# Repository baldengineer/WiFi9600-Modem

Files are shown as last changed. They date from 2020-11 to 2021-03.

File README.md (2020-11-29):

# WiFi9600 Modem
 Retro-cyling a Practical Peripherals 9600SA into a WiFiModem

Design files and code for WiFi9600.

As a kid, I had a Practical Peripherals 9600SA. For years I used it to connect to BBSes and then the Internet. At least, until I upgraded to a 56K USR Sportser.

This project removes the original electronics and replaces them with an ESP8266, MP3 Player, and some relays. It allows classic computers with a RS-232 port to connect to the internet via telnet. 

The MP3 player enables authentic fake modem sounds. And the relays are there for authentic real clicky-clicks.

Live stream archive of the project work is available here:
https://www.twitch.tv/baldengineer/videos

Watch the stream and help out in chat here:
https://twitch.tv/baldengineer

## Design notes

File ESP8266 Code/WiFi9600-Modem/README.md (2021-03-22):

sThe modem firmware is using the code from this project:  https://github.com/dhansel/WifiModem

Modifications include support for LED activity and playing sounds. 

There are also a couple of places where `millis()` isn't handled correctly. (When I'm done with my project, I'll fork and submit a PR.)

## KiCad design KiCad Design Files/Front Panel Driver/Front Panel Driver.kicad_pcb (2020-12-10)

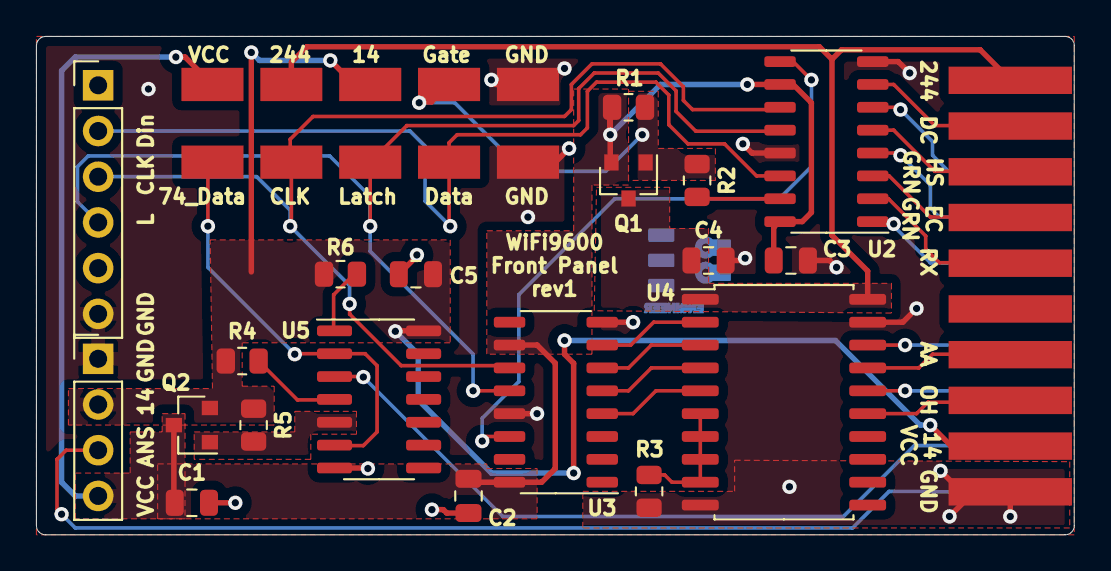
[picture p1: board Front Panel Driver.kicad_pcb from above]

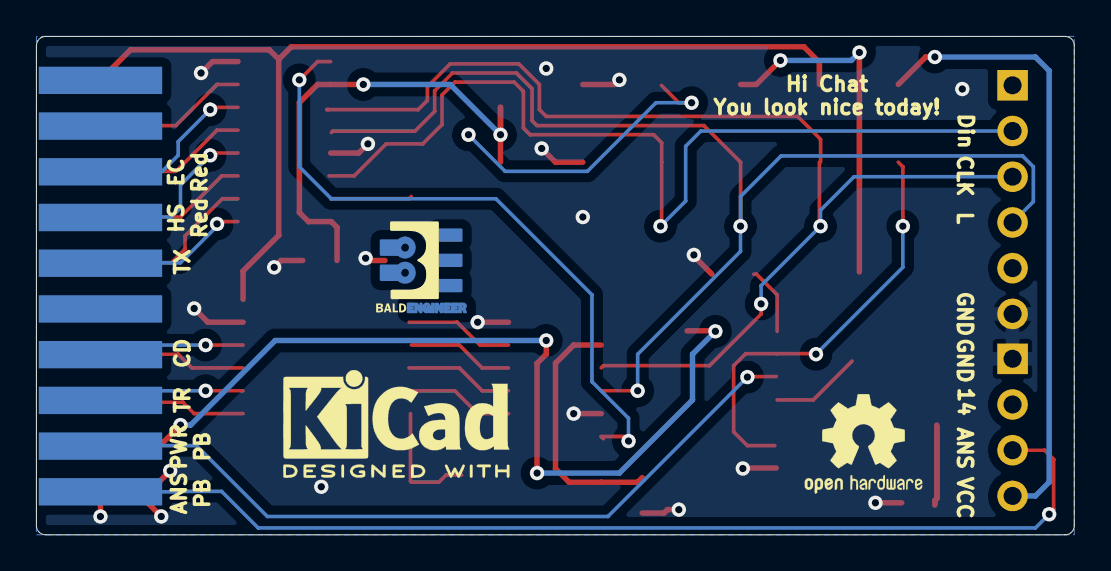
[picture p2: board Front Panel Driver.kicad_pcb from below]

Board: 2 copper layers, 57.7 x 27.7 mm, 31 parts (2 on the bottom side), 32 nets.

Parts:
C1, C2, C3, C4, C5: 1uF; C_0805_2012Metric
J9: Front_Panel; Edge_10mil_2x10
J10: PWR_HDR; PinHeader_1x04_P2.54mm_Vertical
J11: SH_HDR; PinHeader_1x06_P2.54mm_Vertical
Q1, Q2: P-NMOS; SOT-23
R1, R3, R4, R5, R6: 4k7; R_0805_2012Metric
R2: 1k; R_0805_2012Metric
TP1: TP_Panel_EN; Harwin-S1751-46-Test-Point
TP2: TP_244_VCC; Harwin-S1751-46-Test-Point
TP3: Data; Harwin-S1751-46-Test-Point
TP4: Clock; Harwin-S1751-46-Test-Point
TP5: Latch; Harwin-S1751-46-Test-Point
TP6: TP_74_Data; Harwin-S1751-46-Test-Point
TP7: TP_14_VCC; Harwin-S1751-46-Test-Point
TP8: TP_VCC; Harwin-S1751-46-Test-Point
TP9: TP_GND1; Harwin-S1751-46-Test-Point
TP10: TP_GND2; Harwin-S1751-46-Test-Point
U2, U3: 74HCT595; SO-16_3.9x9.9mm_P1.27mm
U4: 74HCT245; SOIC-20W_7.5x12.8mm_P1.27mm
U5: 74HCT74; SOIC-14_3.9x8.7mm_P1.27mm
svg2mod: G***; BE5

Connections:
/14-VCC: C5.1, J9.12, J10.2, Q2.2, R4.1, R5.1, R6.2, TP7.1, U5.14
/244-VCC: C4.1, J9.20, Q1.3, TP2.1, U4.1, U4.20
/AA: J9.14, U4.17
/ANS-PB: J9.10, J10.3
/CD: J9.7, U4.18
/DC: J9.19, U2.7
/Data-In: J11.2, TP3.1, U2.14
/EC-GRN: J9.17, U2.3
/EC-Red: J9.3, U2.6
/FF-DATA: TP6.1, U5.2, U5.6
/Gate244: Q1.1, R1.1, R2.1, TP1.1
/HS-GRN: J9.18, U2.5
/HS-Red: J9.4, U2.4
/Latch: J11.4, TP5.1, U2.12, U3.12
/OH: J9.13, U4.15
/PWR-PB: J9.9, U5.3
/Panel-En: R2.2, U2.15
/RX: J9.16, U2.2
/SH1: U3.4, U4.5
/SH2: U3.5, U4.4
/SH3: U3.6, U4.3
/SH4: U3.7, U4.2
/SH-Carry: U2.9, U3.14
/Ser-Clock: J11.3, TP4.1, U2.11, U3.11
/TR: J9.8, U4.16
/TX: J9.5, U2.1
GND: C1.2, C2.2, C3.2, C4.2, C5.2, J9.11, J10.1, J11.6, R3.2, TP9.1, TP10.1, U2.8, U2.13, U3.8, U3.13, U4.10, U4.19, U5.7
unnamed: Q2.1, R5.2, U5.5
unnamed: R3.1, U4.6, U4.7, U4.8, U4.9
unnamed: R4.2, U5.4
unnamed: R6.1, U5.1
VCC: C1.1, C2.1, C3.1, J10.4, Q1.2, Q2.3, R1.2, TP8.1, U2.10, U2.16, U3.10, U3.16

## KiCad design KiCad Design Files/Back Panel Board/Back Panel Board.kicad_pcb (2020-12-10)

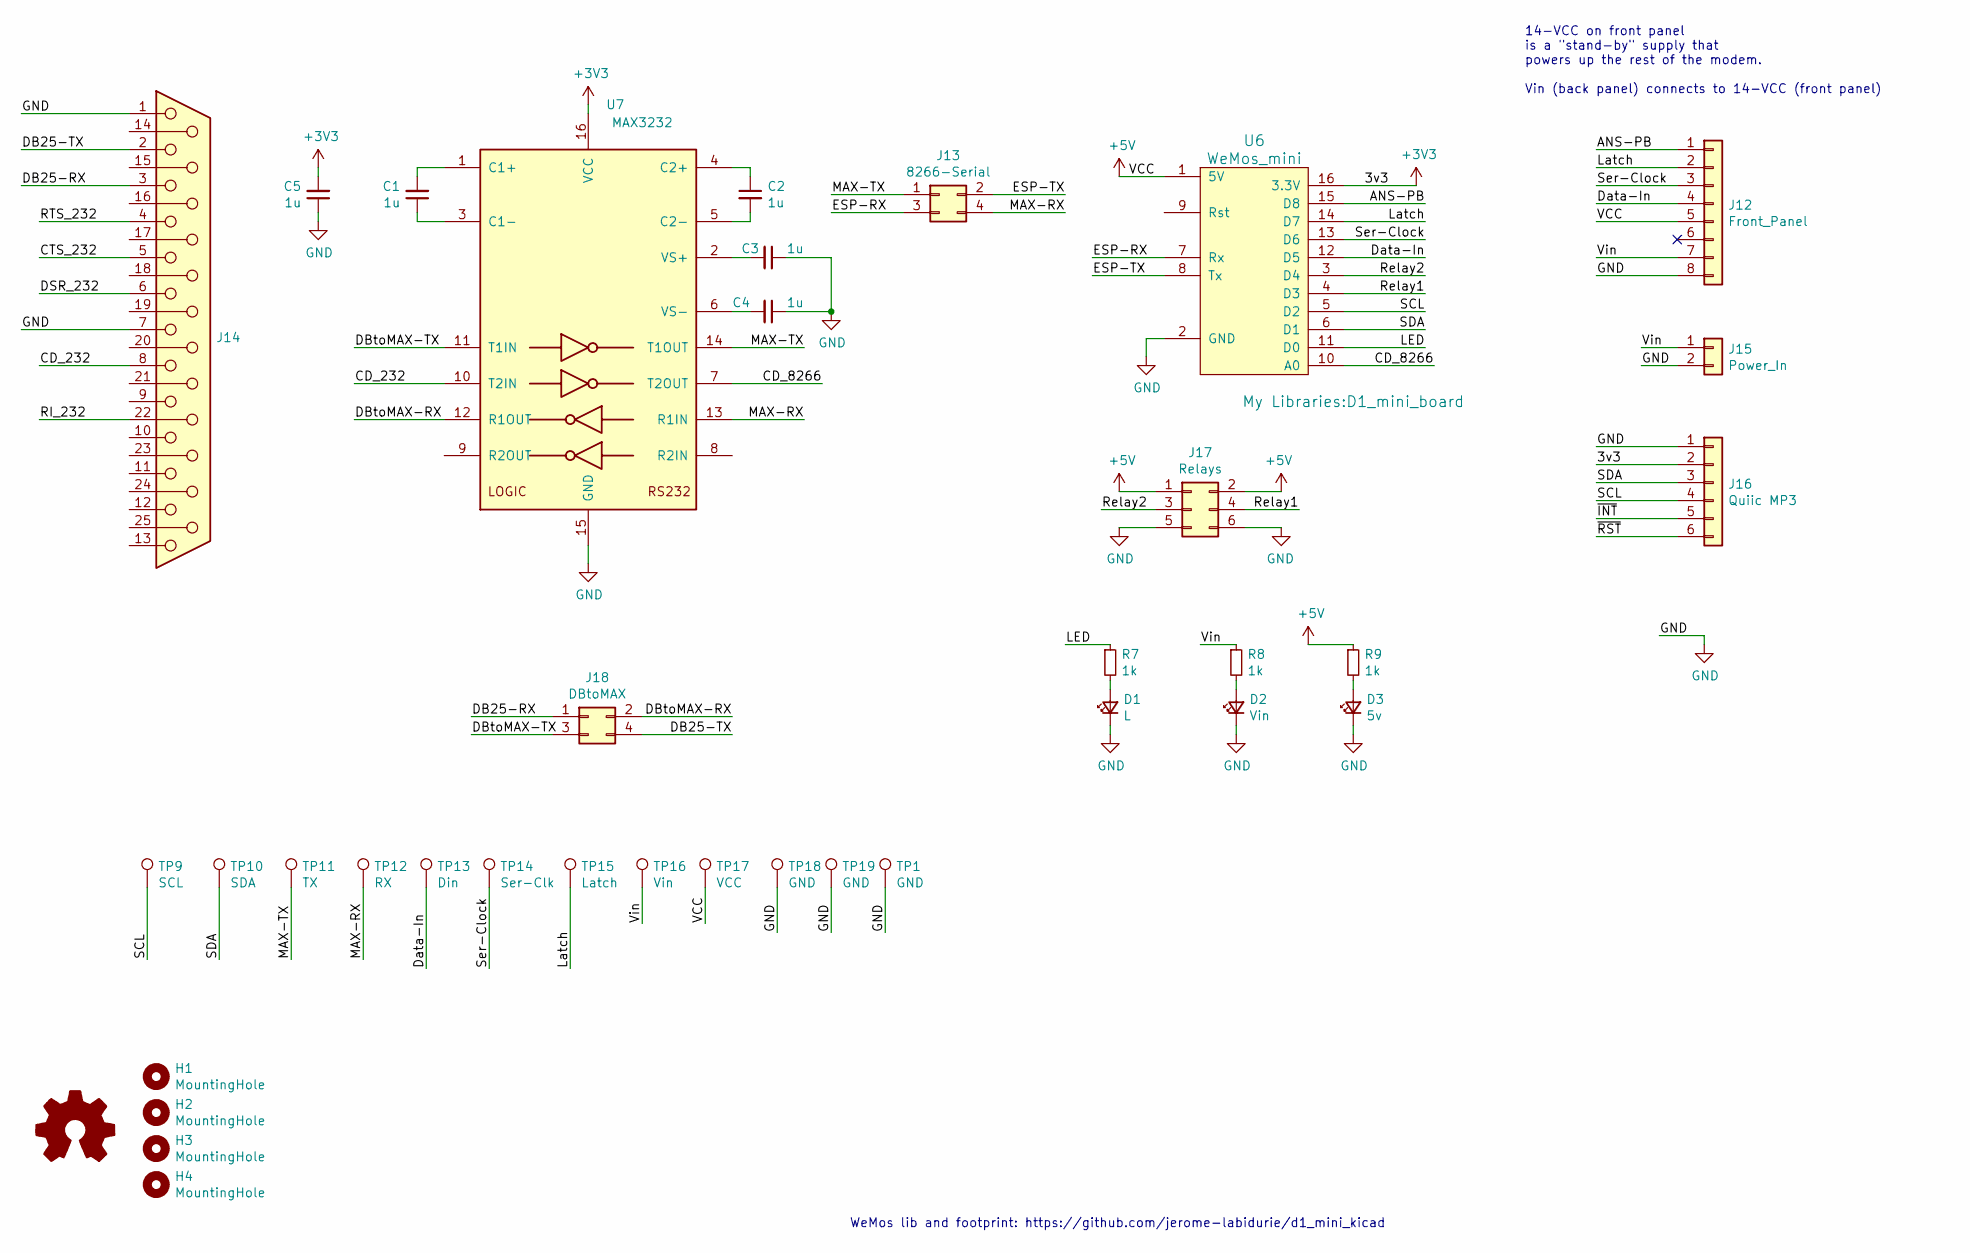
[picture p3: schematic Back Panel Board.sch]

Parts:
C1, C2, C3, C4, C5: 1u; C_0805_2012Metric
D1: L; LED_1206_3216Metric
D2: Vin; LED_1206_3216Metric
D3: 5v; LED_1206_3216Metric
H1, H2, H3, H4: MountingHole; MountingHole_2.5mm
J12: Front_Panel; PinHeader_1x08_P2.54mm_Vertical
J13: 8266-Serial; PinHeader_2x02_P2.54mm_Vertical
J14: DB25_Female_MountingHoles; DSUB-25_Female_EdgeMount_P2.77mm
J15: Power_In; PinHeader_1x02_P2.54mm_Vertical
J16: Quiic MP3; PinHeader_1x06_P2.54mm_Vertical
J17: Relays; PinHeader_2x03_P2.54mm_Vertical
J18: DBtoMAX; PinHeader_2x02_P2.54mm_Vertical
R7, R8, R9: 1k; R_0805_2012Metric
TP1, TP18, TP19: GND; Harwin-S1751-46-Test-Point
TP9: SCL; Harwin-S1751-46-Test-Point
TP10: SDA; Harwin-S1751-46-Test-Point
TP11: TX; Harwin-S1751-46-Test-Point
TP12: RX; Harwin-S1751-46-Test-Point
TP13: Din; Harwin-S1751-46-Test-Point
TP14: Ser-Clk; Harwin-S1751-46-Test-Point
TP15: Latch; Harwin-S1751-46-Test-Point
TP16: Vin; Harwin-S1751-46-Test-Point
TP17: VCC; Harwin-S1751-46-Test-Point
U6: WeMos_mini; D1_mini_board
U7: MAX3232; SOIC-16W_7.5x10.3mm_P1.27mm

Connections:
+3V3: C5.2, J16.2, U6.16 (3.3V), U7.16 (VCC)
+5V: J12.5, J17.1, J17.2, R9.1, TP17.1, U6.1 (5V)
/ANS-PB: J12.1, U6.15 (D8)
/CD_232: J14.8, U7.10 (T2IN)
/CD_8266: U6.10 (A0), U7.7 (T2OUT)
/CTS_232: J14.5
/DB25-RX: J14.3, J18.1
/DB25-TX: J14.2, J18.4
/DBtoMAX-RX: J18.2, U7.12 (R1OUT)
/DBtoMAX-TX: J18.3, U7.11 (T1IN)
/DSR_232: J14.6
/Data-In: J12.4, TP13.1, U6.12 (D5)
/ESP-RX: J13.3, U6.7 (Rx)
/ESP-TX: J13.2, U6.8 (Tx)
/LED: R7.1, U6.11 (D0)
/Latch: J12.2, TP15.1, U6.14 (D7)
/MAX-RX: J13.4, TP12.1, U7.13 (R1IN)
/MAX-TX: J13.1, TP11.1, U7.14 (T1OUT)
/RI_232: J14.22
/RTS_232: J14.4
/Relay1: J17.4, U6.4 (D3)
/Relay2: J17.3, U6.3 (D4)
/SCL: J16.4, TP9.1, U6.5 (D2)
/SDA: J16.3, TP10.1, U6.6 (D1)
/Ser-Clock: J12.3, TP14.1, U6.13 (D6)
/Vin: J12.7, J15.1, R8.1, TP16.1
/~INT: J16.5
/~RST: J16.6
GND: C3.1, C4.1, C5.1, D1.1 (K), D2.1 (K), D3.1 (K), J12.8, J14.1, J14.7, J15.2, J16.1, J17.5, J17.6, TP1.1, TP18.1, TP19.1, U6.2 (GND), U7.15 (GND)
unnamed: C1.1, U7.3 (C1-)
unnamed: C1.2, U7.1 (C1+)
unnamed: C2.1, U7.4 (C2+)
unnamed: C2.2, U7.5 (C2-)
unnamed: C3.2, U7.2 (VS+)
unnamed: C4.2, U7.6 (VS-)
unnamed: D1.2 (A), R7.2
unnamed: D2.2 (A), R8.2
unnamed: D3.2 (A), R9.2

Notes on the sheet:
14-VCC on front panel is a "stand-by" supply that powers up the rest of the modem. Vin (back panel) connects to 14-VCC (front panel)
WeMos lib and footprint: https://github.com/jerome-labidurie/d1_mini_kicad

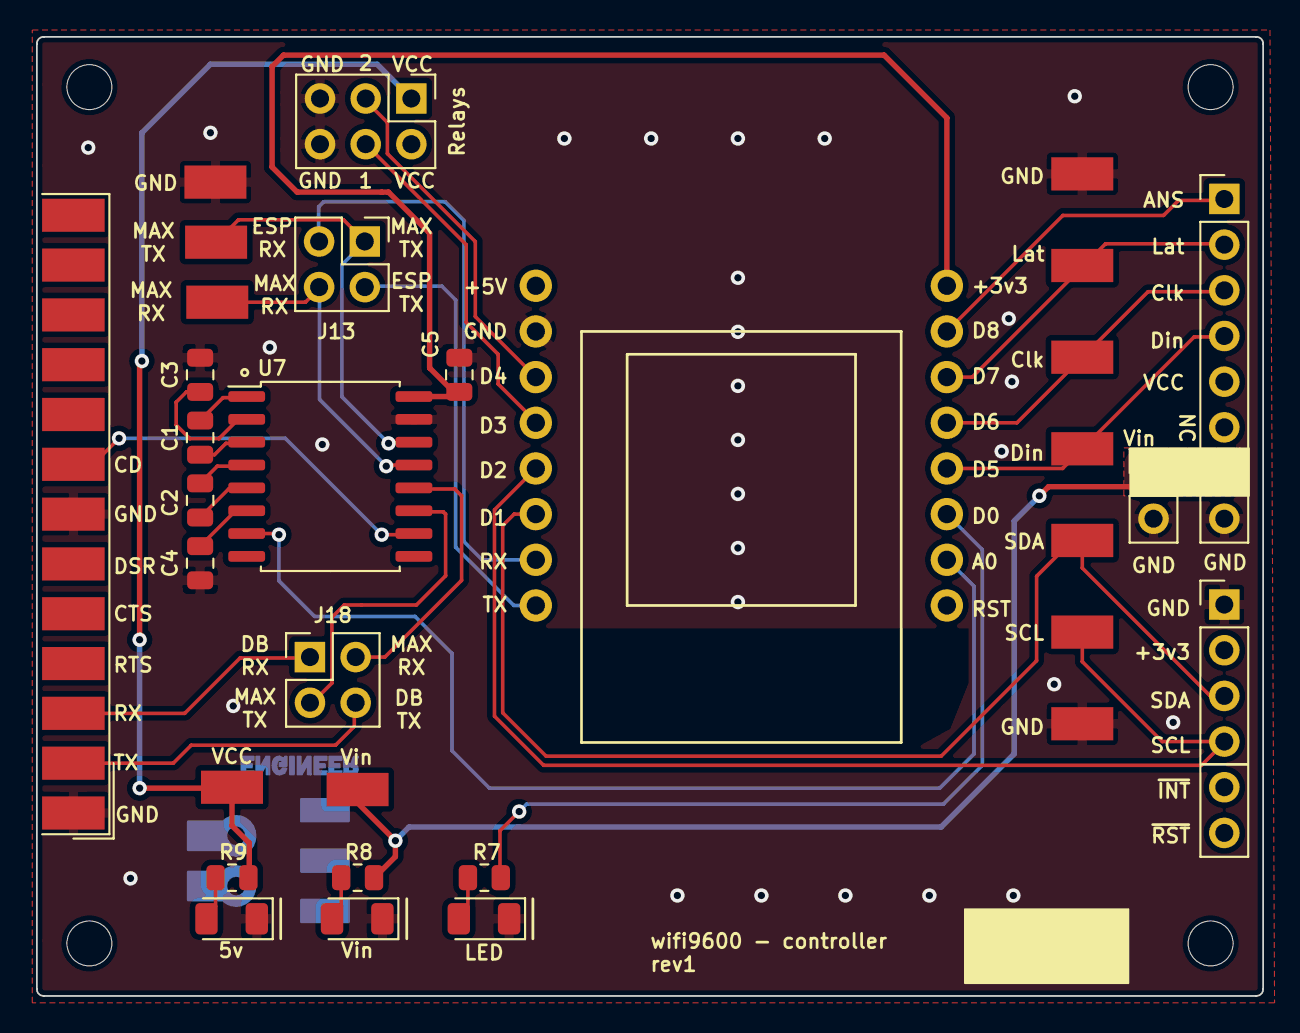
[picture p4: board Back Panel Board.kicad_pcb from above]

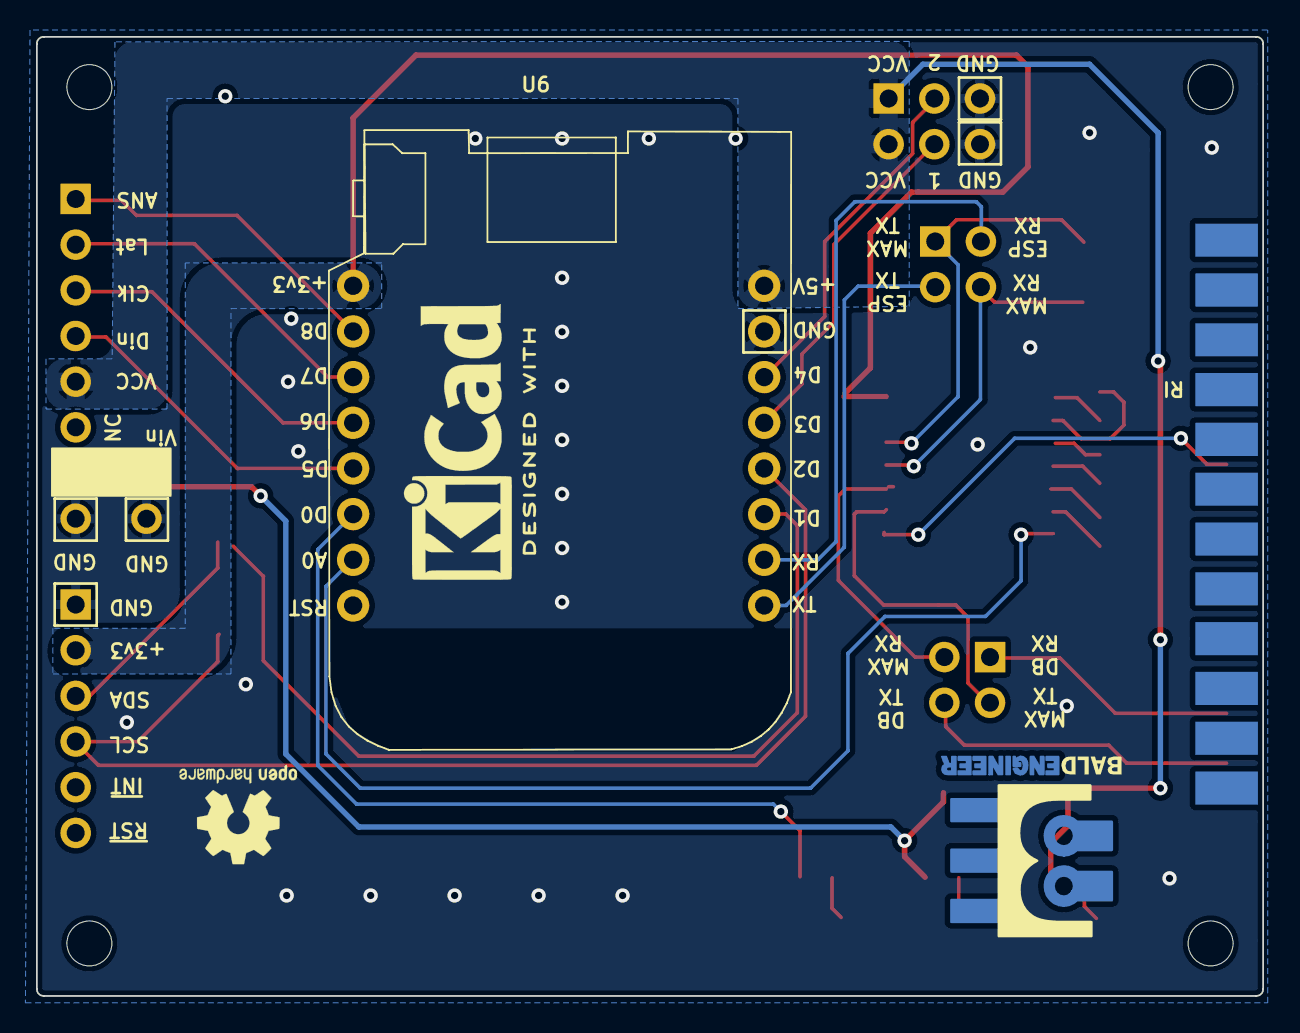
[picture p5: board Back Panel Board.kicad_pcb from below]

Board: 2 copper layers, 68.2 x 53.3 mm, 37 parts (2 on the bottom side), 32 nets.

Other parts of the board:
svg2mod: G***; BE10

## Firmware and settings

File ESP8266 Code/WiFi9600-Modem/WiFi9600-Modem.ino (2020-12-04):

// This code originally based on 
// WiFi Modem and Telnet Server
// Copyright (C) 2018 David Hansel
// -----------------------------------------------------------------------------
// Modifications by James Lewis @baldengineer
// WiFi9600 Practical Perpherials 9600SA Retro Cycling

#include <ESP8266WiFi.h>
#include <ESP8266WebServer.h>
#include <ESP8266mDNS.h>
#include <EEPROM.h>

#include <Wire.h> //Needed for I2C to Qwiic MP3 Trigger

#include "WiFi9600-Modem.h"

//how many clients should be able to telnet to this ESP8266
#define MAX_SRV_CLIENTS 3

WiFiServer server(23);
WiFiClient serverClients[MAX_SRV_CLIENTS], modemClient;
ESP8266WebServer webserver(80);
unsigned long prevCharTime = 0;
uint8_t modemEscapeState = 0, modemExtCodes = 0, modemReg[255];
bool    modemCommandMode = true, modemEcho = true, modemQuiet = false, modemVerbose = true;


static int linespeeds[] = {0, 75, 110, 300, 600, 1200, 2400, 4800, 7200, 9600, 12000, 14400};
#define NSPEEDS (sizeof(linespeeds)/sizeof(int))

#define REG_ESC            2
#define REG_CR             3
#define REG_LF             4
#define REG_BSP            5
#define REG_GUARDTIME     12
#define REG_LINESPEED     37
#define REG_CURLINESPEED  43

#define RELAY_ON LOW
#define RELAY_OFF HIGH

enum  {
    E_OK = 0,
    E_CONNECT,
    E_RING,
    E_NOCARRIER,
    E_ERROR,
    E_CONNECT1200,
    E_NODIALTONE,
    E_BUSY,
    E_NOANSWER,
    E_CONNECT600,
    E_CONNECT2400,
    E_CONNECT4800,
    E_CONNECT9600,
    E_CONNECT14400,
    E_CONNECT19200
  };

struct TelnetStateStruct {
  uint8_t cmdLen;
  uint8_t cmd[4];
  bool sendBinary;
  bool receiveBinary;
  bool receivedCR;
  bool subnegotiation;
} modemTelnetState, clientTelnetState[MAX_SRV_CLIENTS];


#define MAGICVAL 0xF0E1D2C3B4A59687
struct WiFiDataStruct {
  uint64_t magic;
  char     ssid[256];
  char     key[256];
} WifiData;


struct SerialDataStruct {
  uint64_t magic;
  uint32_t baud;
  byte     bits;
  byte     parity;
  byte     stopbits;
  byte     silent;
  byte     handleTelnetProtocol;
  char     telnetTerminalType[100];
} SerialData;


SerialConfig GetSerialConfig() {
  if( SerialData.bits==5 && SerialData.parity==0 && SerialData.stopbits==1 )
    return SERIAL_5N1;
  else if( SerialData.bits==5 && SerialData.parity==0 && SerialData.stopbits==2 )
    return SERIAL_5N2;
  else if( SerialData.bits==5 && SerialData.parity==1 && SerialData.stopbits==1 )
    return SERIAL_5E1;
  else if( SerialData.bits==5 && SerialData.parity==1 && SerialData.stopbits==2 )
    return SERIAL_5E2;
  else if( SerialData.bits==5 && SerialData.parity==2 && SerialData.stopbits==1 )
    return SERIAL_5O1;
  else if( SerialData.bits==5 && SerialData.parity==2 && SerialData.stopbits==2 )
    return SERIAL_5O2;
  else if( SerialData.bits==6 && SerialData.parity==0 && SerialData.stopbits==1 )
    return SERIAL_6N1;
  else if( SerialData.bits==6 && SerialData.parity==0 && SerialData.stopbits==2 )
    return SERIAL_6N2;
  else if( SerialData.bits==6 && SerialData.parity==1 && SerialData.stopbits==1 )
    return SERIAL_6E1;
  else if( SerialData.bits==6 && SerialData.parity==1 && SerialData.stopbits==2 )
    return SERIAL_6E2;
  else if( SerialData.bits==6 && SerialData.parity==2 && SerialData.stopbits==1 )
    return SERIAL_6O1;
  else if( SerialData.bits==6 && SerialData.parity==2 && SerialData.stopbits==2 )
    return SERIAL_6O2;
  else if( SerialData.bits==7 && SerialData.parity==0 && SerialData.stopbits==1 )
    return SERIAL_7N1;
  else if( SerialData.bits==7 && SerialData.parity==0 && SerialData.stopbits==2 )
    return SERIAL_7N2;
  else if( SerialData.bits==7 && SerialData.parity==1 && SerialData.stopbits==1 )
    return SERIAL_7E1;
  else if( SerialData.bits==7 && SerialData.parity==1 && SerialData.stopbits==2 )
    return SERIAL_7E2;
  else if( SerialData.bits==7 && SerialData.parity==2 && SerialData.stopbits==1 )
    return SERIAL_7O1;
  else if( SerialData.bits==7 && SerialData.parity==2 && SerialData.stopbits==2 )
    return SERIAL_7O2;
  else if( SerialData.bits==8 && SerialData.parity==0 && SerialData.stopbits==1 )
    return SERIAL_8N1;
  else if( SerialData.bits==8 && SerialData.parity==0 && SerialData.stopbits==2 )
    return SERIAL_8N2;
  else if( SerialData.bits==8 && SerialData.parity==1 && SerialData.stopbits==1 )
    return SERIAL_8E1;
  else if( SerialData.bits==8 && SerialData.parity==1 && SerialData.stopbits==2 )
    return SERIAL_8E2;
  else if( SerialData.bits==8 && SerialData.parity==2 && SerialData.stopbits==1 )
    return SERIAL_8O1;
  else if( SerialData.bits==8 && SerialData.parity==2 && SerialData.stopbits==2 )
    return SERIAL_8O2;
  else
    return SERIAL_8N1;
}


void applySerialSettings() {
  Serial.flush();
  Serial.end();
  delay(100);
  Serial.begin(SerialData.baud, GetSerialConfig());
}


const int   baud[]   = {110, 150, 300, 600, 1200, 2400, 4800, 9600, 19200, 38400, 57600, 115200, 256000, 512000, 921600, 0};
const int   bits[]   = {5, 6, 7, 8, 0};
const char *parity[] = {"No parity", "Even parity", "Odd parity", NULL};
const char *stop[]   = {"One stop bit", "Two stop bits", NULL};


void handleRoot() {
  char buffer2[100];
  String s;
  int i;

  s = ("<html>\n"
       "<head>\n"
       "<title>ESP8266 Telnet-to-Serial Bridge</title>\n"
       "</head>\n"
       "<body>\n"
       "<h1>ESP8266 Telnet-to-Serial Bridge</h1>\n");

  s += "<h2>Baud rate</h1>\n<ul>\n";
  for(i=0; baud[i]; i++)
    {
      if( (i==0 || baud[i-1]<SerialData.baud) && baud[i] > SerialData.baud )
        {
          snprintf(buffer2, 100, "<li><b>%i baud</b></li>", SerialData.baud);
          s += String(buffer2);
        }
      
      if( baud[i] == SerialData.baud )
        snprintf(buffer2, 100, "<li><b>%i baud</b></li>", baud[i]);
      else 
        snprintf(buffer2, 100, "<li><a href=\"set?baud=%i\">%i baud</a></li>", baud[i], baud[i]);
      
      s += String(buffer2);
    }


  s += "</ul>\n<h2>Data bits</h2>\n<ul>\n";
  for(i=0; bits[i]; i++)
    {
      if( SerialData.bits == bits[i] )
        snprintf(buffer2, 100, "<li><b>%i bits</b></li>", bits[i]);
      else 
        snprintf(buffer2, 100, "<li><a href=\"set?bits=%i\">%i bits</a></li>", bits[i], bits[i]);
      
      s += String(buffer2);
    }


  s += "</ul>\n<h2>Parity</h2>\n<ul>\n";
  for(i=0; parity[i]; i++)
    {
      if( SerialData.parity == i )
        snprintf(buffer2, 100, "<li><b>%s</b></li>", parity[i]);
      else
        snprintf(buffer2, 100, "<li><a href=\"set?parity=%c\">%s</a></li>", parity[i][0], parity[i]);

      s += String(buffer2);
    }

  s += "</ul>\n<h2>Stop bits</h2>\n<ul>\n";
  for(i=0; stop[i]; i++)
    {
      if( SerialData.stopbits == i+1 )
        snprintf(buffer2, 100, "<li><b>%s</b></li>", stop[i]); 
      else 
        snprintf(buffer2, 100, "<li><a href=\"set?stopbits=%i\">%s</a></li>", i+1, stop[i]);

      s += String(buffer2);
    }

  s += "</ul>\n<h2>Show WiFi connection information</h2>\n<ul>\n";
  if( SerialData.silent )
    {
      s += "<li><a href=\"set?silent=no\">Print to serial port after connecting</a></li>\n";
      s += "<li><b>Do not show</b></li>\n";
    }
  else
    {
      s += "<li><b>Print to serial port after connecting</b></li>\n";
      s += "<li><a href=\"set?silent=yes\">Do not show</a></li>\n";
    }
  
  s += "</ul>\n<h2>Telnet protocol</h2>\n<ul>\n";
  if( SerialData.handleTelnetProtocol )
    {
      int i;
      const char *terminalTypes[] = {"none", "ansi", "teletype-33", "unknown", "vt100", "xterm", NULL};

      s += "<li><b>Handle</b> - Report terminal type: ";
      bool found = false;
      for(i=0; terminalTypes[i]!=NULL; i++)
        {
          if( i>0 ) s += ", ";
          if( strcmp(terminalTypes[i], SerialData.telnetTerminalType)==0 || (i==0 && SerialData.telnetTerminalType[0]==0) )
            { s += "<b>" + String(terminalTypes[i]) + "</b>"; found = true; }
          else
            {
              snprintf(buffer2, 100, "<a href=\"set?telnetTerminalType=%s\">%s</a>", terminalTypes[i], terminalTypes[i]);
              s += String(buffer2);
            }
        }

      if( !found ) s += ", <b>" + String(SerialData.telnetTerminalType) + "</b>";
      s += "</li>\n";
      s += "<li><a href=\"set?filterTelnet=no\">Pass through</a></li>\n";
    }
  else
    {
      s += "<li><a href=\"set?filterTelnet=yes\">Handle</a></li>\n";
      s += "<li><b>Pass through</b></li>\n";
    }
  
  s += "</ul>\n</body>\n</html>";
  webserver.send(200, "text/html", s);
}


void handleSet()
{
  bool ok = webserver.args()>0;
  for(int i=0; i<ok && webserver.args(); i++)
    {
      if( webserver.argName(i) == "baud" )
        SerialData.baud = atoi(webserver.arg(i).c_str());
      else if( webserver.argName(i) == "bits" )
        {
          byte bits = atoi(webserver.arg(i).c_str());
          if( bits>=5 && bits<=8 )
            SerialData.bits = bits;
          else
            ok = false;
        }
      else if( webserver.argName(i) == "parity" && webserver.arg(i)=="N" )
        SerialData.parity = 0;
      else if( webserver.argName(i) == "parity" && webserver.arg(i)=="E" )
        SerialData.parity = 1;
      else if( webserver.argName(i) == "parity" && webserver.arg(i)=="O" )
        SerialData.parity = 2;
      else if( webserver.argName(i) == "stopbits" && webserver.arg(i)=="1" )
        SerialData.stopbits = 1;
      else if( webserver.argName(i) == "stopbits" && webserver.arg(i)=="2" )
        SerialData.stopbits = 2;
      else if( webserver.argName(i) == "silent" && webserver.arg(i)=="yes" )
        SerialData.silent = true;
      else if( webserver.argName(i) == "silent" && webserver.arg(i)=="no" )
        SerialData.silent = false;
      else if( webserver.argName(i) == "filterTelnet" && webserver.arg(i)=="log" )
        SerialData.handleTelnetProtocol = 2;
      else if( webserver.argName(i) == "filterTelnet" && webserver.arg(i)=="yes" )
        SerialData.handleTelnetProtocol = 1;
      else if( webserver.argName(i) == "filterTelnet" && webserver.arg(i)=="no" )
        SerialData.handleTelnetProtocol = 0;
      else if( webserver.argName(i) == "telnetTerminalType" )
        {
          int j;
          String ts = webserver.arg(i);
          for(j=0; j<99 && j<ts.length() && ts[j]>=32 && ts[j]<127; j++)
            SerialData.telnetTerminalType[j] = ts[j];
          SerialData.telnetTerminalType[j] = 0;
        }
      else
        ok = false;
    }

  if( ok ) 
    {
      EEPROM.put(768, SerialData);
      EEPROM.commit();
      applySerialSettings();
    }

  handleRoot();
}


void handleNotFound() 
{
  String message = "File Not Found\n\n";
  message += "URI: ";
  message += webserver.uri();
  message += "\nMethod: ";
  message += (webserver.method() == HTTP_GET) ? "GET" : "POST";
  message += "\nArguments: ";
  message += webserver.args();
  message += "\n";

  for (uint8_t i = 0; i < webserver.args(); i++)
    message += " " + webserver.argName(i) + ": " + webserver.arg(i) + "\n";

  webserver.send(404, "text/plain", message);
}


void readString(char *buffer, int buflen, bool password)
{
  int len = 0;
  while( true )
  {
    if( Serial.available() )
      {
        char c = Serial.read();
        if( c==10 || c==13 )
          {
            buffer[len] = 0;
            //Serial.print("Password: '");
            //Serial.print(buffer);
            //Serial.println("'");
            return;
          }
        else if( (c==8 || c==127) && len>0 )
          {
            Serial.print(char(8)); Serial.print(' '); Serial.print(char(8));
            len--;
          }
        else if( c >= 32 && len<buflen-1 )
          {
            buffer[len++] = c;
            Serial.print(password ? '*' : c);
          }
      }
    else
      delay(10);
    
    yield();
  }
  
}


void clearSerialBuffer()
{
  // empty the serial buffer
  delay(100); 
  while( Serial.available()>0 ) { Serial.read(); delay(10); }
}


void GetWiFiData(const char *msg)
{
  clearSerialBuffer();

  bool go = true;
  while( go )
  {
     Serial.println(msg); 
     Serial.println("Press C to configure WiFi connection information.\n");
     
     unsigned long t = millis()+2000;
     while( millis()<t ) if( Serial.available()>0 && Serial.read()=='C' ) { go = false; break; }
     yield();
  }

  Serial.println("Scanning for networks...");

  WiFi.disconnect();
  int n = WiFi.scanNetworks();
  if (n == 0) {
    Serial.println("No networks found.");
  } else {
    Serial.print(n);
    Serial.println(" networks found:");
    for (int i = 0; i < n; ++i) {
      Serial.print(i + 1);
      Serial.print(": ");
      Serial.print(WiFi.SSID(i));
      Serial.print(" (");
      Serial.print(WiFi.RSSI(i));
      Serial.print(")");
      Serial.println((WiFi.encryptionType(i) == ENC_TYPE_NONE) ? " " : "*");
      delay(10);
    }
  }
  Serial.println("\n");
  WiFi.disconnect();

  clearSerialBuffer();
  Serial.print("SSID: ");
  readString(WifiData.ssid, 256, false);
  Serial.println();

  clearSerialBuffer();
  Serial.print("Password: ");
  readString(WifiData.key, 256, true);
  Serial.println();

  WifiData.magic = MAGICVAL;
  SerialData.silent = false;
  EEPROM.put(0, WifiData);
  EEPROM.put(768, SerialData);
  EEPROM.commit();
}

void init_eeprom_serial() {
  EEPROM.begin(1024);
  EEPROM.get(768, SerialData);
  if( SerialData.magic != MAGICVAL ) {
      // use default settings
      SerialData.baud     = 9600;
      SerialData.bits     = 8;
      SerialData.parity   = 0;
      SerialData.stopbits = 1;
      SerialData.silent   = false;
      SerialData.handleTelnetProtocol = 1;
      SerialData.magic    = MAGICVAL;
      strcpy(SerialData.telnetTerminalType, "vt100");
      EEPROM.put(768, SerialData);
      EEPROM.commit();
    } else {
      // make sure terminal type string is ASCII and 0-terminated
      int i = 0;
      while(i<99 && SerialData.telnetTerminalType[i]>=32 && SerialData.telnetTerminalType[i]<127) i++;
      SerialData.telnetTerminalType[i]=0;
    }
}

void start_WiFi_interface() {
  while( WiFi.status() != WL_CONNECTED ) {
    WiFi.begin(WifiData.ssid, WifiData.key);
    uint8_t i = 0;

    // try to connect to WiFi
    while(WiFi.status() != WL_CONNECTED && i++ < 20 ) {
      delay(250);
      digitalWrite(led_pin, HIGH); 
      delay(250);
      digitalWrite(led_pin, LOW); 
      if( Serial.available()>0 && Serial.read() == 27 ) break;
    }

    if( WiFi.status() != WL_CONNECTED ) {
      char buffer[300];
      if( i == 21 )
        sprintf(buffer, "Could not connect to %s.", WifiData.ssid);
      else
        sprintf(buffer, "Received ESC during connect.");
        
      GetWiFiData(buffer);
    }
  }
}

bool haveTelnetClient() {
  for( int i=0; i<MAX_SRV_CLIENTS; i++ )
    if( serverClients[i] && serverClients[i].connected() )
      return true;

  return false;
}

void resetTelnetState(struct TelnetStateStruct &s){
  s.cmdLen = 0;
  s.sendBinary = false;
  s.receiveBinary = false;
  s.receivedCR = false;
  s.subnegotiation = false;
}


void resetModemState() {
  const uint8_t regDefaults[] = {2, '+', 
                                 3, '\r', 
                                 4, '\n', 
                                 5, 8, 
                                 6, 2, 
                                 7, 50, 
                                 8, 2, 
                                 9, 6, 
                                 10, 14, 
                                 11, 95, 
                                 12, 50, 
                                 25, 5,
                                 38, 20};

  for(int i=0; i<256; i++) modemReg[i] = 0;
  for(int i=0; i<sizeof(regDefaults); i+=2) modemReg[regDefaults[i]] = regDefaults[i+1];

  modemEscapeState = 0;
  modemExtCodes = 0;
  modemCommandMode = true;
  modemEcho = true;
  modemQuiet = false;
  modemVerbose = true;
  
  if( modemClient.connected() ) modemClient.stop();
}


void printModemCR() {
  Serial.print(char(modemReg[REG_CR]));
  if( modemVerbose ) Serial.print(char(modemReg[REG_LF]));
}

void connect_lights(uint16_t HSled, bool state) {
    update_led(ECgrn, TURN_ON, false);
    update_led(ECred, TURN_ON, true);
    update_led(DC, TURN_ON, true); 
    update_led(HSled, state, true);
}

void printModemResult(byte code) {
  if (code == E_CONNECT) {
  }

  if (code == E_NOCARRIER) {
    toggle_relay();
    all_led_state(TURN_OFF);
  }
  switch(code) {
    case E_CONNECT1200: 
    case E_CONNECT2400: 
    case E_CONNECT4800:
    case E_CONNECT: 
      connect_lights(HSred, TURN_ON); 
      break;
    case E_CONNECT9600:
    case E_CONNECT14400:
    case E_CONNECT19200: 
      connect_lights(HSgrn, TURN_ON); 
      break;
  }

  if( !modemQuiet )
    {
      if( modemVerbose )
        {
          printModemCR();
          switch( code ) {
            case E_OK            : Serial.print("OK");             break;
            case E_CONNECT       : Serial.print("CONNECT");        break;
            case E_RING          : Serial.print("RING");           break;
            case E_NOCARRIER     : Serial.print("NO CARRIER");     break;
            case E_ERROR         : Serial.print("ERROR");          break;
            case E_CONNECT1200   : Serial.print("CONNECT 1200");   break;
            case E_NODIALTONE    : Serial.print("NO DIALTONE");    break;
            case E_BUSY          : Serial.print("BUSY");           break;
            case E_NOANSWER      : Serial.print("NO ANSWER");      break;
            case E_CONNECT600    : Serial.print("CONNECT 600");    break;
            case E_CONNECT2400   : Serial.print("CONNECT 2400");   break;
            case E_CONNECT4800   : Serial.print("CONNECT 4800");   break;
            case E_CONNECT9600   : Serial.print("CONNECT 9600");   break;
            case E_CONNECT14400  : Serial.print("CONNECT 14400");  break;
            default:
              {
                char buf[20];
                sprintf(buf, "ERROR%i", code);
                Serial.print(buf);
                break;
              }
            }
        }
      else
        Serial.print(code);

      printModemCR();
    }
}


byte getCmdParam(char *cmd, int &ptr) {
  byte res = 0;

  ptr++;
  if( isdigit(cmd[ptr]) ) {
      int p = ptr;
      while( isdigit(cmd[ptr]) ) ptr++;
      char c = cmd[ptr];
      cmd[ptr] = 0;
      res = atoi(cmd+p);
      cmd[ptr] = c;
    }
  
  return res;
}


// returns TRUE if input byte "b" is part of a telnet protocol sequence and should
// NOT be passed through to the serial interface
bool handleTelnetProtocol(uint8_t b, WiFiClient &client, struct TelnetStateStruct &state) {
#define T_SE      240 // 0xf0
#define T_NOP     241 // 0xf1
#define T_BREAK   243 // 0xf3
#define T_GOAHEAD 249 // 0xf9
#define T_SB      250 // 0xfa
#define T_WILL    251 // 0xfb
#define T_WONT    252 // 0xfc
#define T_DO      253 // 0xfd
#define T_DONT    254 // 0xfe
#define T_IAC     255 // 0xff
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
void loop() {
  uint8_t i;

  // check if ANSWER pushbutton has been pressed
  bool current_ans_pb_state = digitalRead(ans_pushbutton);

  if (previous_ans_pb_state != current_ans_pb_state) {
    if (current_ans_pb_state == PRESSED) {
      if (modemClient.connected())
        modemClient.stop();
      update_led(AA, TURN_ON, true);
    } else {
      update_led(AA, TURN_OFF, true);
    }
    previous_ans_pb_state = current_ans_pb_state;
  }

  // let the user know the modem is connected to WiFi
  if (WiFi.status() == WL_CONNECTED){
    if (!(led_states & TR))  // only send the "on" command once
      update_led(TR, TURN_ON, true);
  } else {
      update_led(TR, TURN_OFF, true);
  }

  if( modemClient && modemClient.connected() ) {
      activity_decay();
      // modem is connected. if telnet server has new client then reject
      if( server.hasClient() ) server.available().stop();

      // only relay data if not in command mode
      if( !modemCommandMode ) relayModemData();
    } else {
      // check whether connection to modem client was lost
      if( !modemCommandMode ) {
          modemClient.stop();
          modemCommandMode = true;
          modemReg[REG_CURLINESPEED] = 0;
          printModemResult(E_NOCARRIER);
        }

      // check if there are any new telnet clients
      if( server.hasClient() ) {
          // find free/disconnected spot
          for( i=0; i<MAX_SRV_CLIENTS; i++ ) {
              if( !serverClients[i] || !serverClients[i].connected() )  {
                  serverClients[i] = server.available();
                  resetTelnetState(clientTelnetState[i]);
                  break;
                }
            }
          
          //no free/disconnected spot so reject
          if( i == MAX_SRV_CLIENTS ) {
              WiFiClient serverClient = server.available();
              serverClient.stop();
            }
        }
    }

  if( haveTelnetClient() )
    relayTelnetData();
  else if( modemCommandMode )
    handleModemCommand();

  webserver.handleClient();
}

// WiFi Modem and Telnet Server
// Copyright (C) 2018 David Hansel
//
// This program is free software; you can redistribute it and/or modify
// it under the terms of the GNU General Public License as published by
// the Free Software Foundation; either version 3 of the License, or
// (at your option) any later version.
//
// This program is distributed in the hope that it will be useful,
// but WITHOUT ANY WARRANTY; without even the implied warranty of
// MERCHANTABILITY or FITNESS FOR A PARTICULAR PURPOSE.  See the
// GNU General Public License for more details.
//
// You should have received a copy of the GNU General Public License
// along with this program; if not, write to the Free Software Foundation,
// Inc., 51 Franklin Street, Fifth Floor, Boston, MA 02110-1301  USA
// -----------------------------------------------------------------------------

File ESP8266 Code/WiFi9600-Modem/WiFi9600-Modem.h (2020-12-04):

// @baldengineer
// WiFi9600 Modem 
// from livestreams twitch.tv/baldengineer
//

/* The digital pins map to these numbers, for whatever reason
TX 	TXD 	TXD
RX 	RXD 	RXD
A0 	Analog input, max 3.2V 	A0

D0 	IO 	GPIO16
D1 	IO, GPIO5 	SCL 
D2 	IO, GPIO4 	SDA 	
D3 	IO, GPIO0	10k Pull-up 	
D4 	IO, GPIO2 	10k Pull-up, BUILTIN_LED 	
D5 	IO, GPIO14	SCK 	
D6 	IO, GPIO12 	MISO 	
D7 	IO, GPIO13	MOSI 	
D8 	IO, 10k Pull-down, SS 	GPIO15

*/

#include "SparkFun_Qwiic_MP3_Trigger_Arduino_Library.h" //http://librarymanager/All#SparkFun_MP3_Trigger
MP3TRIGGER mp3;
byte speaker_volume = 24;

const byte ans_pushbutton = 0; // D3, on pcb: relay1

// clicky-click noise makers
//const byte relay1 = 15; // D8 on pcb: ANS_PB
const byte pots_relay = 2; // D4
bool relay_state = false;

const byte led_pin = 16; // D0

// for the sparkfun mp3 player
const byte i2c_SCL = 4; //D1
const byte i2c_SDA = 5; //D2

// lonely incoming signal from RS232
const byte carrier_detect = A0;

// shift register on front panel
const byte latch_595 = 13; //13 - D7
const byte clock_595 = 12; //12 - D6
const byte data_595 = 14;  //14 - D5

// track answer pushbutton
bool previous_ans_pb_state = false;
#define     PRESSED 0x0
#define NOT_PRESSED 0x1

// LED states, to make code more readable
#define TURN_ON  true
#define TURN_OFF false
// activity indicator 
bool TX_state = TURN_OFF;
bool RX_state = TURN_OFF;

// bit pattern for led_states
#define PANEL_EN 0x7FFF
#define CD    0x0001 //!
#define AA    0x0002 //!
#define TR    0x0004 //!
#define OH    0x0008 //!
#define DC	  0x0100 
#define HSgrn 0x0400
#define HSred 0x0800
#define ECgrn 0x1000
#define ECred 0x0200
#define RX    0x2000 //!
#define TX    0x4000 //!

// The 11 LEDs, including bi-color. Visual top
// to bottom order:
uint16_t front_leds[11] = {TR, TX, RX, OH, CD, AA, HSgrn, HSred, ECgrn, ECred, DC};

// Need 16 bits because of the two shift registers.
// 4 bits not used. Signals are wired as:
// EN TX RX ECgrn   HSred HSgrn ECred DC   X X X X   OH TR AA CD
uint16_t led_states = 0x0000;

// millis() variabled for random_led() to simulate activity
unsigned long previous_activity = 0;

// millis() for TX and RX activity
unsigned long previous_TX_act = 0;
unsigned long previous_RX_act = 0;
unsigned long TX_activity_interval = 0;
unsigned long activity_interval = 47; // may need separate intervals for RX and TX

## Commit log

2020-11-29 Post-stream
    Combined code from previous streams and identified spots to control the LEDs. Blocked by bad Wemos modules. (Logic side of 8266 works, but the WiFi radio isn't functioning.)
2020-12-04 ans pb disconnects modem
    Add same functionality as original modem. When a connection is active, the "answer" button disconnects the modem.
2020-12-10 kicad files with v1 mistakes
    [Back Panel Board-v0-before placing parts.kicad_pcb, Back Panel Board.kicad_pcb, Back Panel Board.sch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]
